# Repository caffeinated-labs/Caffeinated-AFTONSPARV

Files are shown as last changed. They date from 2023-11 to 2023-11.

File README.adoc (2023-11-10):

= Caffeinated AFTONSPARV

This small PCB replaces the original board inside your https://www.ikea.com/us/en/p/aftonsparv-led-decorative-light-planet-shape-multicolor-20559209/[AFTONSPARV Planet lamp].
It connects to your smart home setup via a common ESP32 firmware like https://esphome.io[esphome.io] or https://kno.wled.ge[WLED].

And the best thing, it's all OSHW certified: https://certification.oshwa.org/de000140.html[DE000140]

[#img-OSHW-DE000140,link=https://certification.oshwa.org/de000140.html]
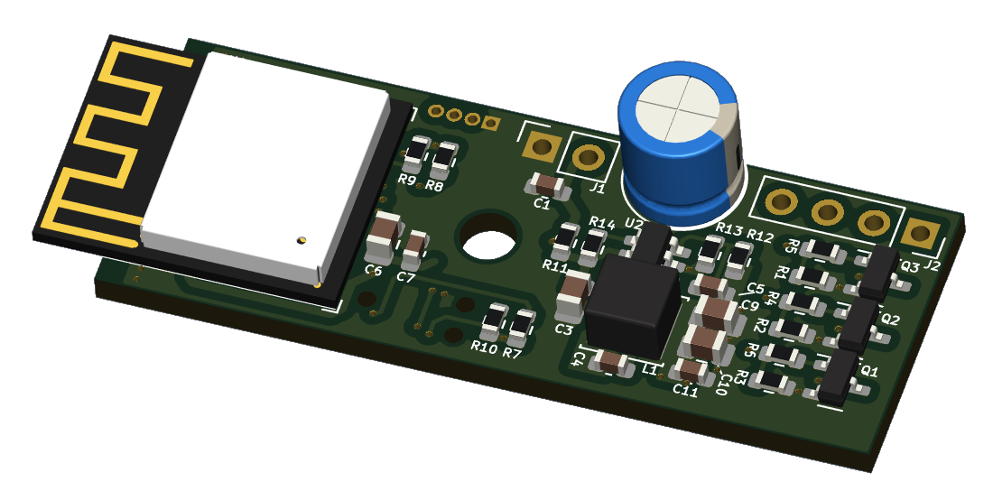
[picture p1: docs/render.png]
KiCad 3D render of the pcb
 OSHW-DE000140
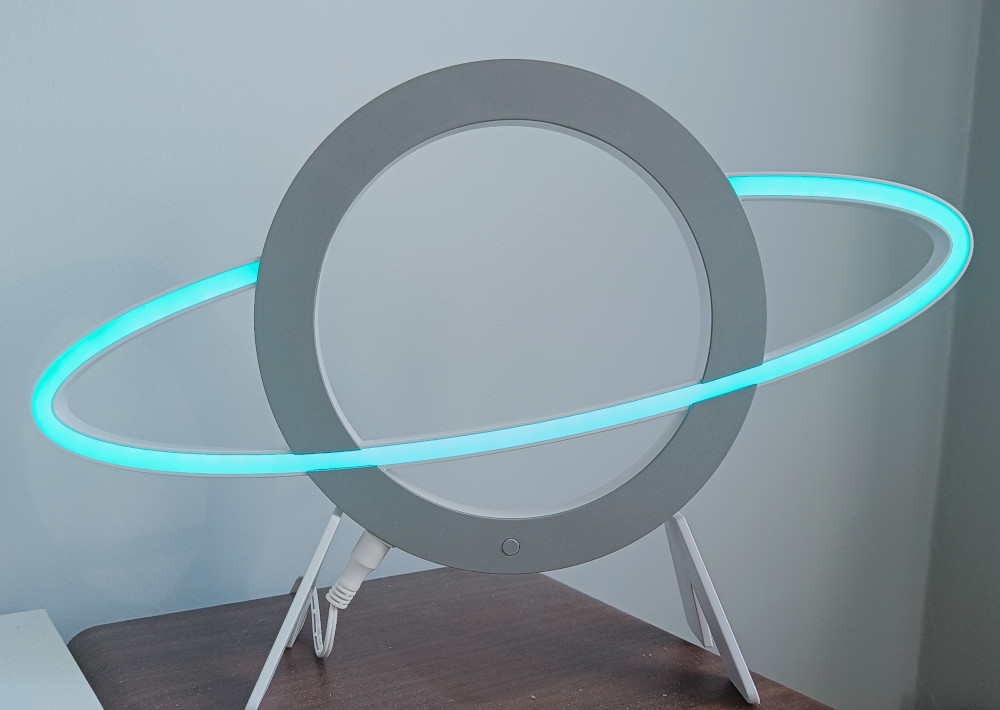
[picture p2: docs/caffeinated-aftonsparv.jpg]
Caffeinated AFTONSPARV


== Instructions

=== Step 1: Remove the cover
Remove the bottom cover from the AFTONSPARV lamp, there is no need to open the top cover. Open the marked screws, there's one under the sticker.

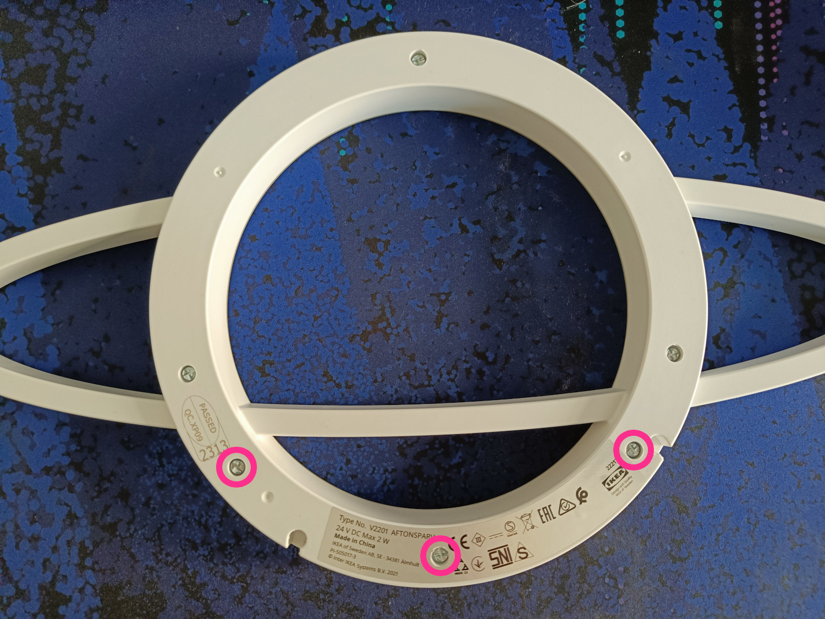
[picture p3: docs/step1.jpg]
The bottom screws are highlited


=== Step 2: Disconnect the wires
Carefully de-solder all wires from the old board, it is not needed anymore.

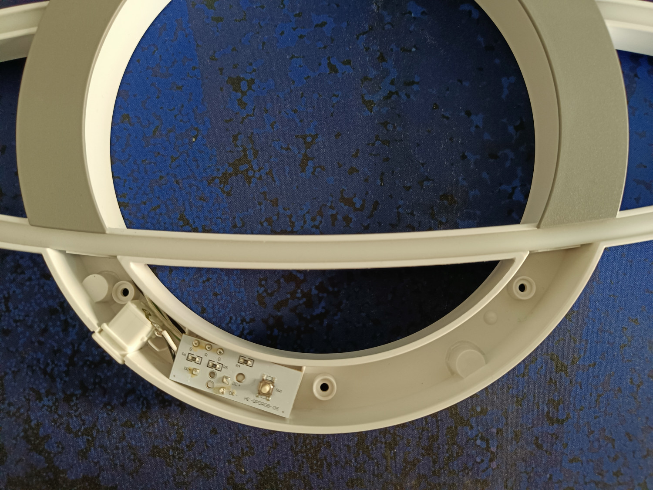
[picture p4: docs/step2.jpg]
Front of the lamp with the cover removed. The original pcb is visible


=== Step 3: Connect the PCB
Carefully solder the wires to the Caffeinated AFTONSPARV as shown below:

|===
| IKEA Lamp | PCB

|LED, black | LED R
|LED, green | LED G
|LED, transparent | LED B
|LED, white | LED {plus}

|Plug, white | POWER {plus}
|Plug, black | POWER -
|===
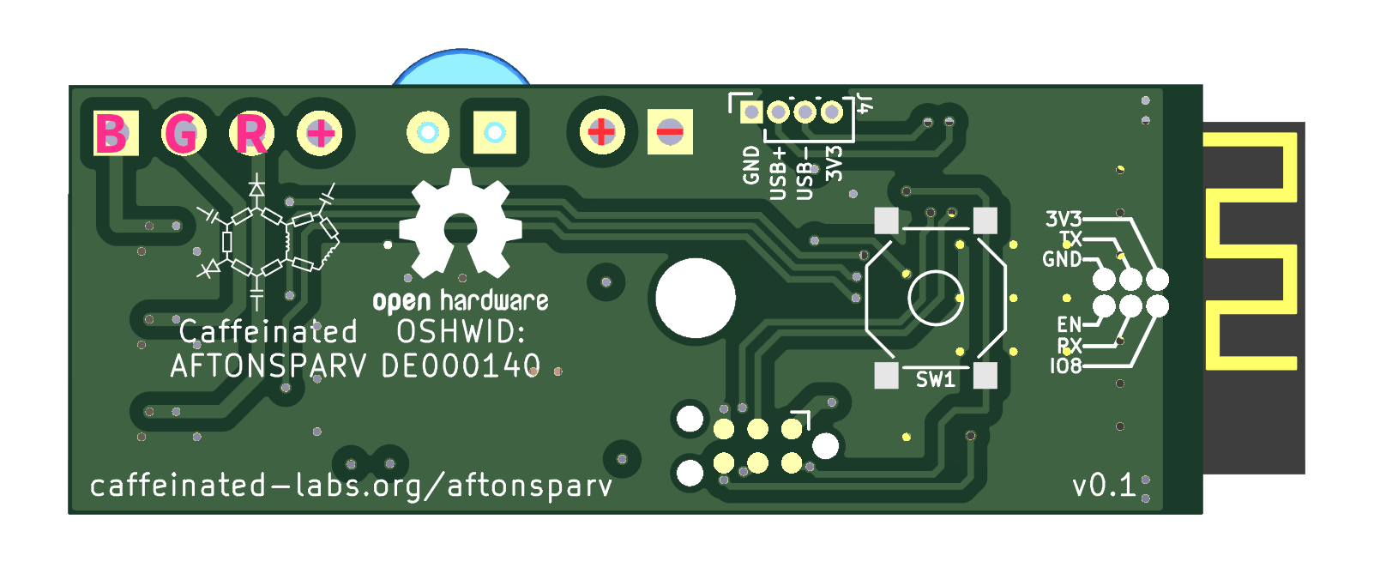
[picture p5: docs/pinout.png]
LED and Power connections

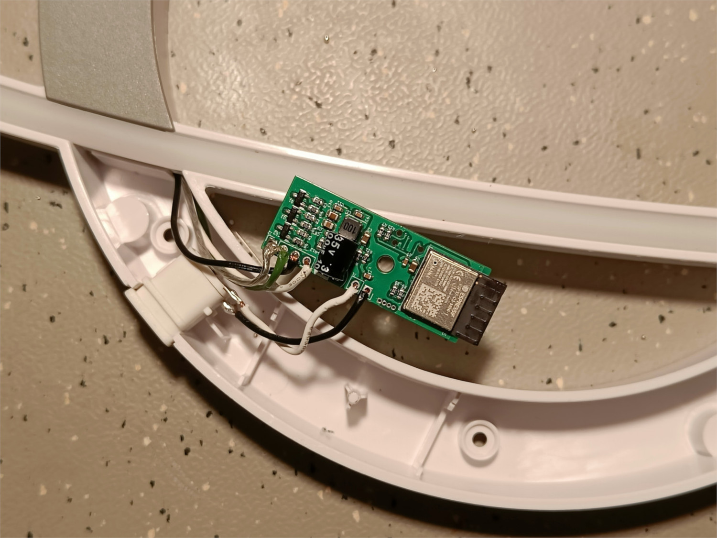
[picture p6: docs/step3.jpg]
All wires connected to the PCB


See <<PinOut>> for more details

=== Step 4: Test
Connect the power and test the PCB.
If nothing gets hot, you can measure 3.3V at the USB Port continue with the firmware installation

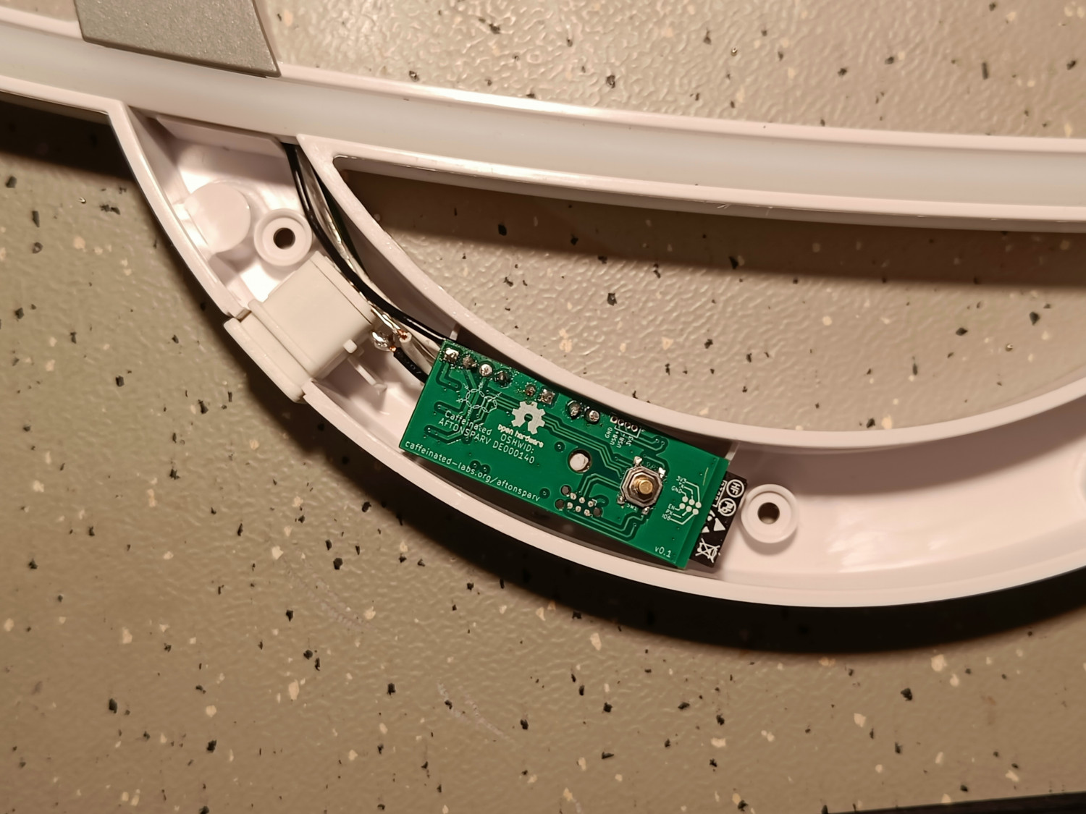
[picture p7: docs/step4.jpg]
The PCB inside the lamp


=== Step 5: Install firmware
Connect the ESP to your computer using the TagConnect or USB interface and install the firmware of your choosing. The button on the front is connected to `IO9`, the boot-mode selectorfootnote:boot-mode[https://www.espressif.com/sites/default/files/documentation/esp32-c3-mini-1_datasheet_en.pdf#table.4].

IMPORTANT: The board *must* be powered with 24V to install firmware.

See <<Firmware>> and <<PinOut>> for more details

=== Step 6: Close it up
Carefully screw-on the cover and enjoy your new and _caffeinated_ lamp.

== PinOut

=== UART
NOTE: The diagram on the PCB v0.1 shows `IO8` - it is connected to `IO9`!

To upload software you can use the standard workflow using `esptool.py` footnote:esptool[https://docs.espressif.com/projects/esptool/en/latest/esp32/] just like any other ESP32 board. The UART interface is exposed on the TagConnect port:

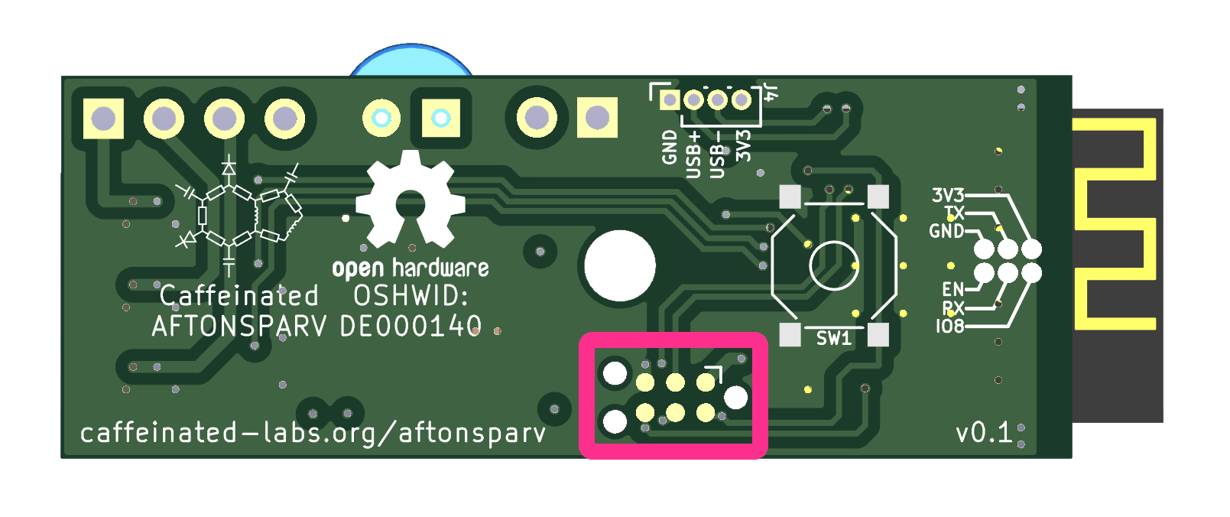
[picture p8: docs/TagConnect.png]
TagConnect location
 TagConnect pinout

It is recommended to use this https://github.com/Jana-Marie/USB-UART-BRIDGE[programmer from @Jana-Marie]

=== USB
In addition, the USB interface is exposed as well. It is located on the edge next to the 24V input. Please remember that the ESP32 uses 3.3V and *not* the usual 5V.

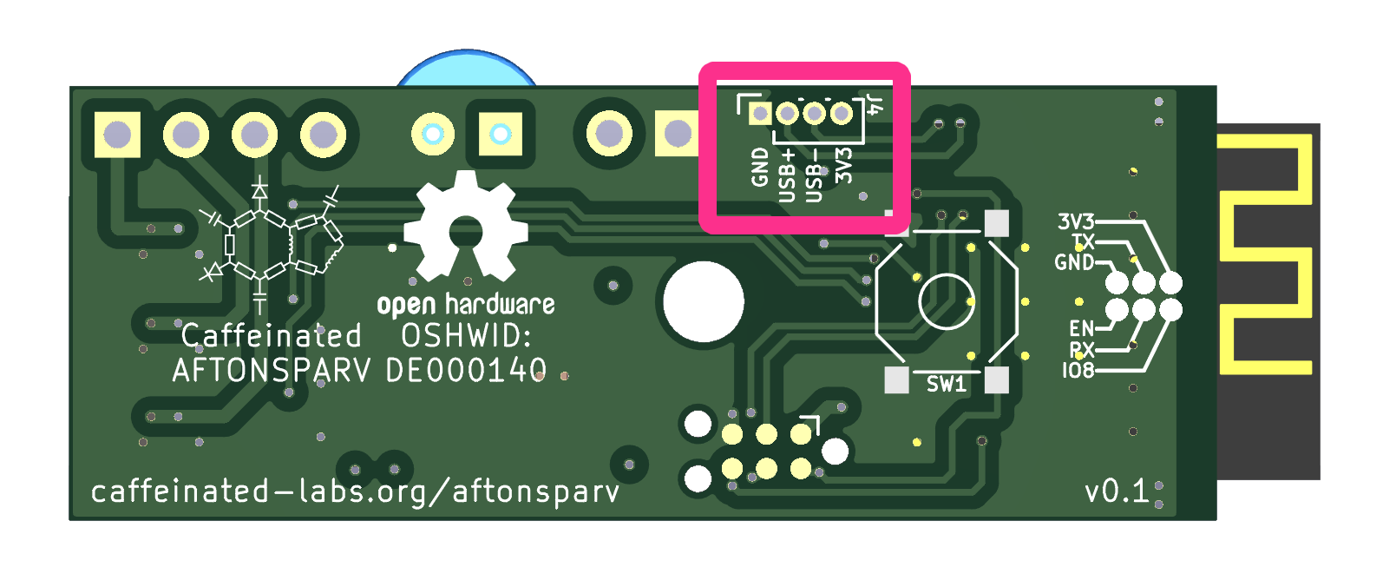
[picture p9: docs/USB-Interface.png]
USB Interace


=== Boot Mode
The front button as well as the <<UART>> interface is connected to `IO9`, which is the boot mode selector (on older models `IO0`) on this ESP32footnote:boot-mode[]. Pressing the button or connecting it to ground puts the ESP into _Download Boot_ mode. Now you can install firmware via <<UART>> or <<USB>>

=== Power & LED
NOTE: On v0.1 the LEDs and Power connections are not labeled on the silkscreen.

Connect the AFTONSPARVs LEDs to the left ports as shown and the power input to the right most *big* connections, connecting to the USB Port will destroy the ESP.

LED and Power connections

== Firmware
=== WLED
==== Installation
[%hardbreaks]
Installing the WLED firmware is easies with their web installer: https://install.wled.me/[install.wled.me]
When installing with `esptool` footnote:esptool[] follow this guide and use the ESP32-C3 binary: https://kno.wled.ge/basics/install-binary/[kno.wled.ge/basics/install-binary]
**Important:** Install this https://install.wled.me/bin/release_0_14_0/esp32-c3_bootloader_v2.bin[ESP32-C3 bootloader] *not* the ESP32 bootlader.

==== Configuration
[%hardbreaks]
LED Preferences > Hardware setup
*1*: `PWM RGB`
*Index*: `0`
*GPIOs*: `4`, `5`, `6`

*Button 0 GPIO*: `9`, `Pushbutton`

.Show screenshot
[%collapsible]
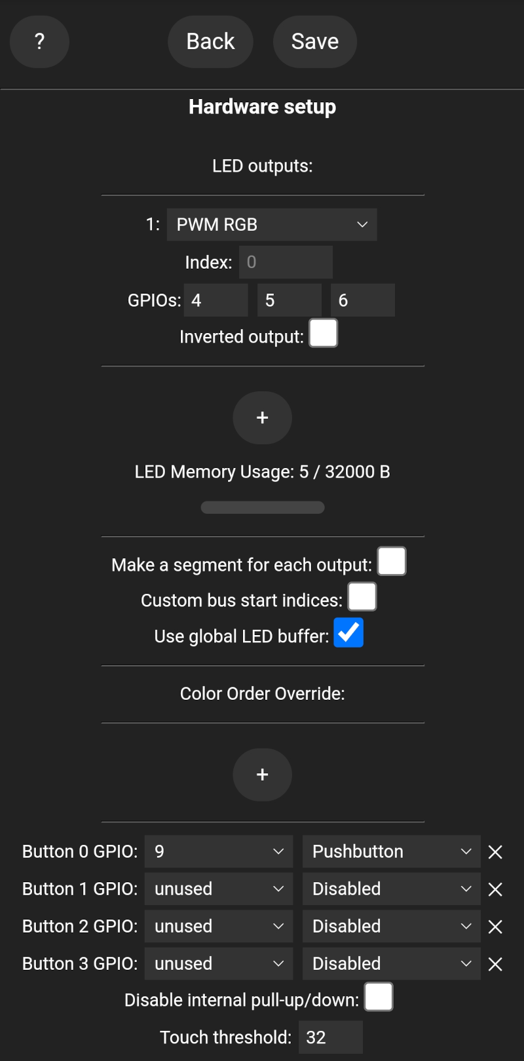
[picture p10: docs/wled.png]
The above setting in the WLED interface


== Hardware

IMPORTANT: It is not possible to hand-solder this project, it requires a hot-air station or reflow oven. It is recommended to use a stencil for solder paste.

=== BOM

|===
| Reference         | Value                  | Qty | LCSC

|C1, C4, C7, C11    | 100nF                  | 4   | C14663
|C2                 | 100µF 35V              | 1   | C2831717
|C3, C6, C9, C10    | 4.7uF                  | 4   | C560882
|C5                 | 22pF                   | 1   | C105620
|L1                 | 10uH                   | 1   | C38117
|Q1-Q3              | AO3400A                | 3   | C347475
|R1-R3, R7-R10, R14 | 10kΩ                   | 8   | C98220
|R4-R6              | 20Ω                    | 3   | C22950
|R11                | 1Ω                     | 1   | C22936
|R12                | 100kΩ                  | 1   | C25803
|R13                | 22.1kΩ                 | 1   | C25961
|SW1                | SW_Push                | 1   | C2910748
|U1                 | ESP32-C3-MINI-1-[H/N]4 | 1   | C2934569 / C2838502
|U2                 | SY8201ABC              | 1   | C108052
|===

link:bom/ibom.html[BOM Tool]

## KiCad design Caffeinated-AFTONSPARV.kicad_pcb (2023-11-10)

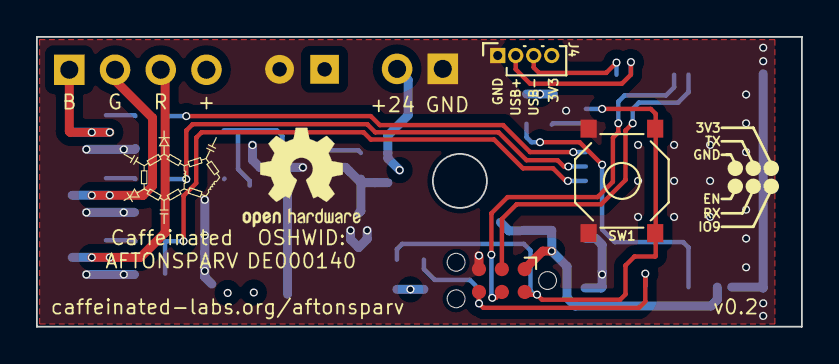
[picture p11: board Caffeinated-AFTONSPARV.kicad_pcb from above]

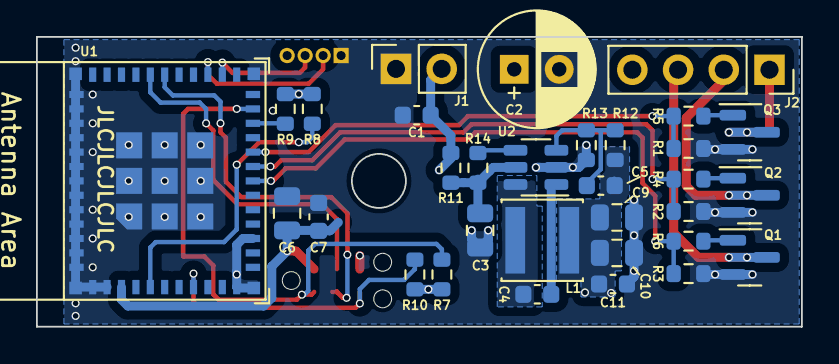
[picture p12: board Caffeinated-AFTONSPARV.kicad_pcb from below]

Board: 4 copper layers, 42.5 x 16.1 mm, 35 parts (32 on the bottom side), 25 nets.

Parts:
C1, C4, C7, C11: 100nF; C_0603_1608Metric
C2: 100µF 35V; CP_Radial_D6.3mm_P2.50mm
C3, C6, C9, C10: 4.7uF; C_0805_2012Metric
C5: 22pF; C_0603_1608Metric
J1: PWR; PinSocket_1x02_P2.54mm_Vertical
J2: LED; PinSocket_1x04_P2.54mm_Vertical
J3: TagConnect; Tag-Connect_TC2030-IDC-NL_2x03_P1.27mm_Vertical
J4: USB; PinSocket_1x04_P1.00mm_Vertical
L1: 10uH; L_Sunlord_SWPA4030S
Q1, Q2, Q3: AO3400A; SOT-23
R1, R2, R3, R7, R8, R9, R10, R14: 10kΩ; R_0603_1608Metric
R4, R5, R6: 20Ω; R_0603_1608Metric
R11: 1Ω; R_0603_1608Metric
R12: 100kΩ; R_0603_1608Metric
R13: 22.1kΩ; R_0603_1608Metric
SW1: SW_Push; YTS-C005
U1: ESP32-C3-MINI-1-[H/N]4; ESP32-C3-MINI-1
U2: SY8201ABC; SOT-23-6

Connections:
+3.3V: C5.2, C6.1, C7.1, C9.1, C10.1, C11.1, J3.1 (VCC), J4.4, L1.2, R7.1, R8.1, R9.1, R10.1, R12.1, U1.3 (3V3)
+24V: C1.1, C2.1, J1.2, J2.4, R11.1
EN: J3.6 (EN), R10.2, U1.8 (EN/CHIP_PU)
GND: C1.2, C2.2, C3.2, C6.2, C7.2, C9.2, C10.2, C11.2, J1.1, J3.5 (GND), J4.1, Q1.2 (S), Q2.2 (S), Q3.2 (S), R1.2, R2.2, R3.2, R13.2, SW1.1, U1.1 (GND), U1.2 (GND), U1.11 (GND), U1.14 (GND), U1.36 (GND), U1.37 (GND), U1.38 (GND), U1.39 (GND), U1.40 (GND), U1.41 (GND), U1.42 (GND), U1.43 (GND), U1.44 (GND), U1.45 (GND), U1.46 (GND), U1.47 (GND), U1.48 (GND), U1.49 (GND), U1.50 (GND), U1.51 (GND), U1.52 (GND), U1.53 (GND), U2.2 (GND)
IO9: J3.2 (IO0/IO9), R7.2, SW1.2, U1.23 (GPIO9)
LED-B: R1.1, R5.1, U1.20 (GPIO6)
LED-G: R2.1, R4.1, U1.19 (GPIO5/ADC2_CH0)
LED-R: R3.1, R6.1, U1.18 (GPIO4/ADC1_CH4)
unnamed: J2.1, Q3.3 (D)
unnamed: J2.2, Q2.3 (D)
unnamed: J2.3, Q1.3 (D)
unnamed: Q1.1 (G), R6.2
unnamed: Q2.1 (G), R4.2
unnamed: Q3.1 (G), R5.2
unnamed: R8.2, U1.5 (GPIO2/ADC1_CH2)
unnamed: R9.2, U1.22 (GPIO8)
unnamed: C4.2, U2.1 (BS)
unnamed: R14.2, U2.4 (EN)
unnamed: C5.1, R12.2, R13.1, U2.3 (FB)
unnamed: C3.1, R11.2, R14.1, U2.5 (IN)
unnamed: C4.1, L1.1, U2.6 (LX)
RX: J3.4 (RX), U1.30 (GPIO20/U0RXD)
TX: J3.3 (TX), U1.31 (GPIO21/U0TXD)
USB-D+: J4.2, U1.27 (GPIO19/USB_D+)
USB-D-: J4.3, U1.26 (GPIO18/USB_D-)

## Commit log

2023-10-09 feat(): Initial commit
    [Caffeinated-AFTONSPARV.kicad_pcb, Caffeinated-AFTONSPARV.kicad_sch]
2023-10-11 feat(): Finalize design
    [Caffeinated-AFTONSPARV.kicad_pcb, Caffeinated-AFTONSPARV.kicad_sch]
2023-10-13 feat(): Rework pcb to 4 layers
    [Caffeinated-AFTONSPARV.kicad_pcb, Caffeinated-AFTONSPARV.kicad_sch]
2023-10-17 feat(): Rework and finalize design
    [Caffeinated-AFTONSPARV.kicad_pcb, Caffeinated-AFTONSPARV.kicad_sch]
2023-10-18 feat(): Replace L1 footprint and add Refs
    [Caffeinated-AFTONSPARV.kicad_pcb, Caffeinated-AFTONSPARV.kicad_sch]
2023-10-25 refactor(): Move vias
    [Caffeinated-AFTONSPARV.kicad_pcb]
2023-10-29 feat(pcb): Set drill pos and export settings
    [Caffeinated-AFTONSPARV.kicad_pcb]
2023-10-29 feat(bom): Add ibom tool
2023-11-01 fix(silkscreen): Add labels to all connections, correct errors and bump number
    [Caffeinated-AFTONSPARV.kicad_pcb]
2023-11-01 fix(3d-render): Hide connectors in the render
    [Caffeinated-AFTONSPARV.kicad_pcb]
2023-11-10 feat(): Update silkscreen, ibom, use smaller sw
    [Caffeinated-AFTONSPARV.kicad_pcb, Caffeinated-AFTONSPARV.kicad_sch]
